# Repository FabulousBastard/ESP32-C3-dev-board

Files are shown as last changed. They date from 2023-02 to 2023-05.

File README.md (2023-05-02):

# ESP32-C3-dev-board

does not work
  - get's power 
  - isn't recognized by Windows
  
 possibel reasons 
  - soldering error
  - PCB design 
  - wong part's selection 
  - software issue 

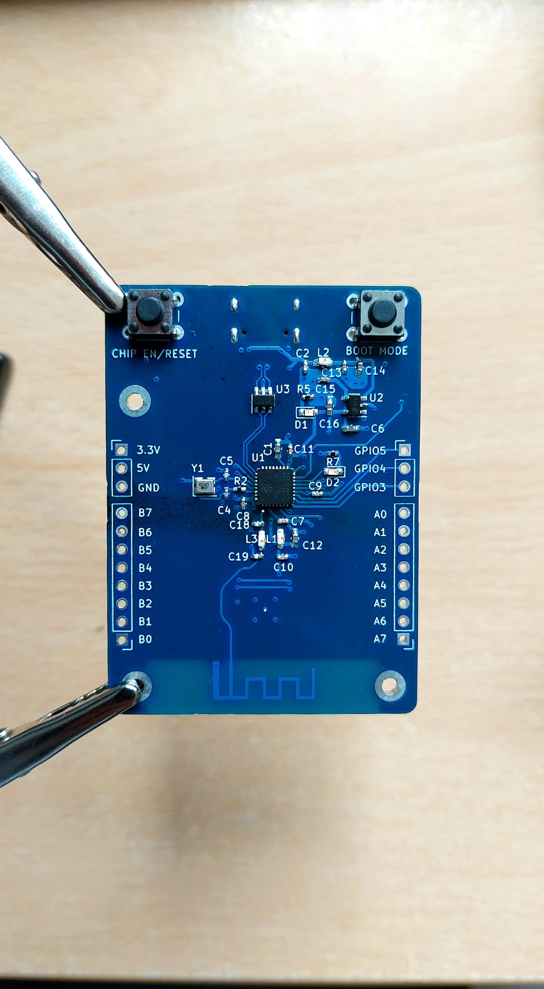
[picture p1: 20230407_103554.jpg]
  

  

  



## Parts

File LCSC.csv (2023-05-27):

LCSC Part Number | Manufacture Part Number | Manufacturer | Customer NO. | Package | Description | RoHS | Order Qty. | Min\Mult Order Qty. | Unit Price | Order Price
C319148 | U262-161N-4BVC11 | XKB Connectivity | 001 | SMD | 3A USB 3.1 1 260℃ Surface Mount 16 Female -40℃~+85℃ Gold Copper Alloy Type-C SMD USB Connectors ROHS | YES | 2 | 1\1 | 0.402600 | 0.81
C2858491 | ESP32-C3FH4 | Espressif Systems | 001 | QFN-32-EP(5x5) | QFN-32-EP(5x5) RF Transceiver ICs ROHS | YES | 2 | 1\1 | 1.968000 | 3.94
C9055 | SPX3819M5-L-3-3/TR | MaxLinear | 001 | SOT-23-5 | 500mA 70dB Fixed 3.3V~3.3V Positive 16V SOT-23-5 Linear Voltage Regulators (LDO) ROHS | YES | 5 | 5\5 | 0.167900 | 0.84
C7519 | USBLC6-2SC6 | STMicroelectronics | 001 | SOT-23-6 | 6V 17V Unidirectional 5.25V SOT-23-6 ESD Protection Devices ROHS | YES | 5 | 5\5 | 0.128900 | 0.64
C2940200 | TAXM40M4SCBDDT2T | TAE(Zhejiang Abel Elec) | 001 | SMD2520-4P | 40MHz 9pF ±10ppm SMD2520-4P Crystals ROHS | YES | 5 | 5\5 | 0.110700 | 0.55
C455091 | TS-1002-05026 | XUNPU | 001 | Plugin,6x6mm | 50mA Straight SPST 12V Plugin,6x6mm Tactile Switches ROHS | YES | 10 | 10\10 | 0.040400 | 0.40
C346308 | FEC0603CP-2N2G-LRH | PSA(Prosperity Dielectrics) | 001 | 0603 | 700mA 2.2nH ±2% 5mΩ 0603 Inductors (SMD) ROHS | YES | 10 | 10\10 | 0.041400 | 0.41
C2337 | C2337 | BOOMELE(Boom Precision Elec) | 001 | Plugin,P=2.54mm | 3A Straight Square Pins -25℃~+85℃ 40 2.54mm Plugin Black 1x40P Plugin,P=2.54mm Pin Headers ROHS | YES | 5 | 5\5 | 0.113700 | 0.57
C2846646 | SML-311UTT86J | ROHM Semicon | 001 | 0603 | -30℃~+85℃ 620nm~630nm Orange-red 44mW 0603 Light Emitting Diodes (LED) ROHS | YES | 5 | 5\5 | 0.143900 | 0.72
C2980184 | 19-217/GHC-YN1P2B18X/3T | Everlight Elec | 001 | 0603 | Colorless transparence -40℃~+85℃ Positive post 520nm~535nm Emerald 120° 95mW 0603 Light Emitting Diodes (LED) ROHS | YES | 5 | 5\5 | 0.087100 | 0.44
C321446 | RC-02W3240FT | FH (Guangdong Fenghua Advanced Tech) | 001 | 0402 | 62.5mW ±1% ±200ppm/℃ 324Ω 0402 Chip Resistor - Surface Mount ROHS | YES | 100 | 100\100 | 0.000400 | 0.04
C25543 | 0402WGJ0102TCE | UNI-ROYAL(Uniroyal Elec) | 001 | 0402 | 62.5mW Thick Film Resistors ±100ppm/℃ ±5% 1kΩ 0402 Chip Resistor - Surface Mount ROHS | YES | 200 | 100\100 | 0.000400 | 0.08
C25152 | 0402WGJ0220TCE | UNI-ROYAL(Uniroyal Elec) | 001 | 0402 | 62.5mW Thick Film Resistors ±100ppm/℃ ±5% 22Ω 0402 Chip Resistor - Surface Mount ROHS | YES | 100 | 100\100 | 0.000400 | 0.04
C2906948 | FRC0402J512 TS | FOJAN | 001 | 0402 | 62.5mW Thick Film Resistors ±100ppm/℃ ±5% 5.1kΩ 0402 Chip Resistor - Surface Mount ROHS | YES | 100 | 100\100 | 0.000500 | 0.05
C123483 | 0402N3R3B500CT | Walsin Tech Corp | 001 | 0402 | 50V 3.3pF NP0 0402 Multilayer Ceramic Capacitors MLCC - SMD/SMT ROHS | YES | 100 | 100\100 | 0.002200 | 0.22
C161507 | GRM1552C1H8R0BA01D | Murata Electronics | 001 | 0402 | 50V 8pF CH 0402 Multilayer Ceramic Capacitors MLCC - SMD/SMT ROHS | YES | 50 | 50\50 | 0.006900 | 0.35
C392963 | TCC0402X7R104K160AT | CCTC | 001 | 0402 | 16V 100nF X7R ±10% 0402 Multilayer Ceramic Capacitors MLCC - SMD/SMT ROHS | YES | 100 | 100\100 | 0.000900 | 0.09
C5252392 | V106M0402X5R100NCT | VIIYONG | 001 | 0402 | 10V 10uF X5R 0402 Multilayer Ceramic Capacitors MLCC - SMD/SMT ROHS | YES | 50 | 50\50 | 0.009700 | 0.49
C629442 | MCP23S17T-E/ML | Microchip Tech | 001 | QFN-28-EP(6x6) | 10MHz SPI QFN-28-EP(6x6) I/O Expanders ROHS | YES | 2 | 1\1 | 5.956400 | 11.91

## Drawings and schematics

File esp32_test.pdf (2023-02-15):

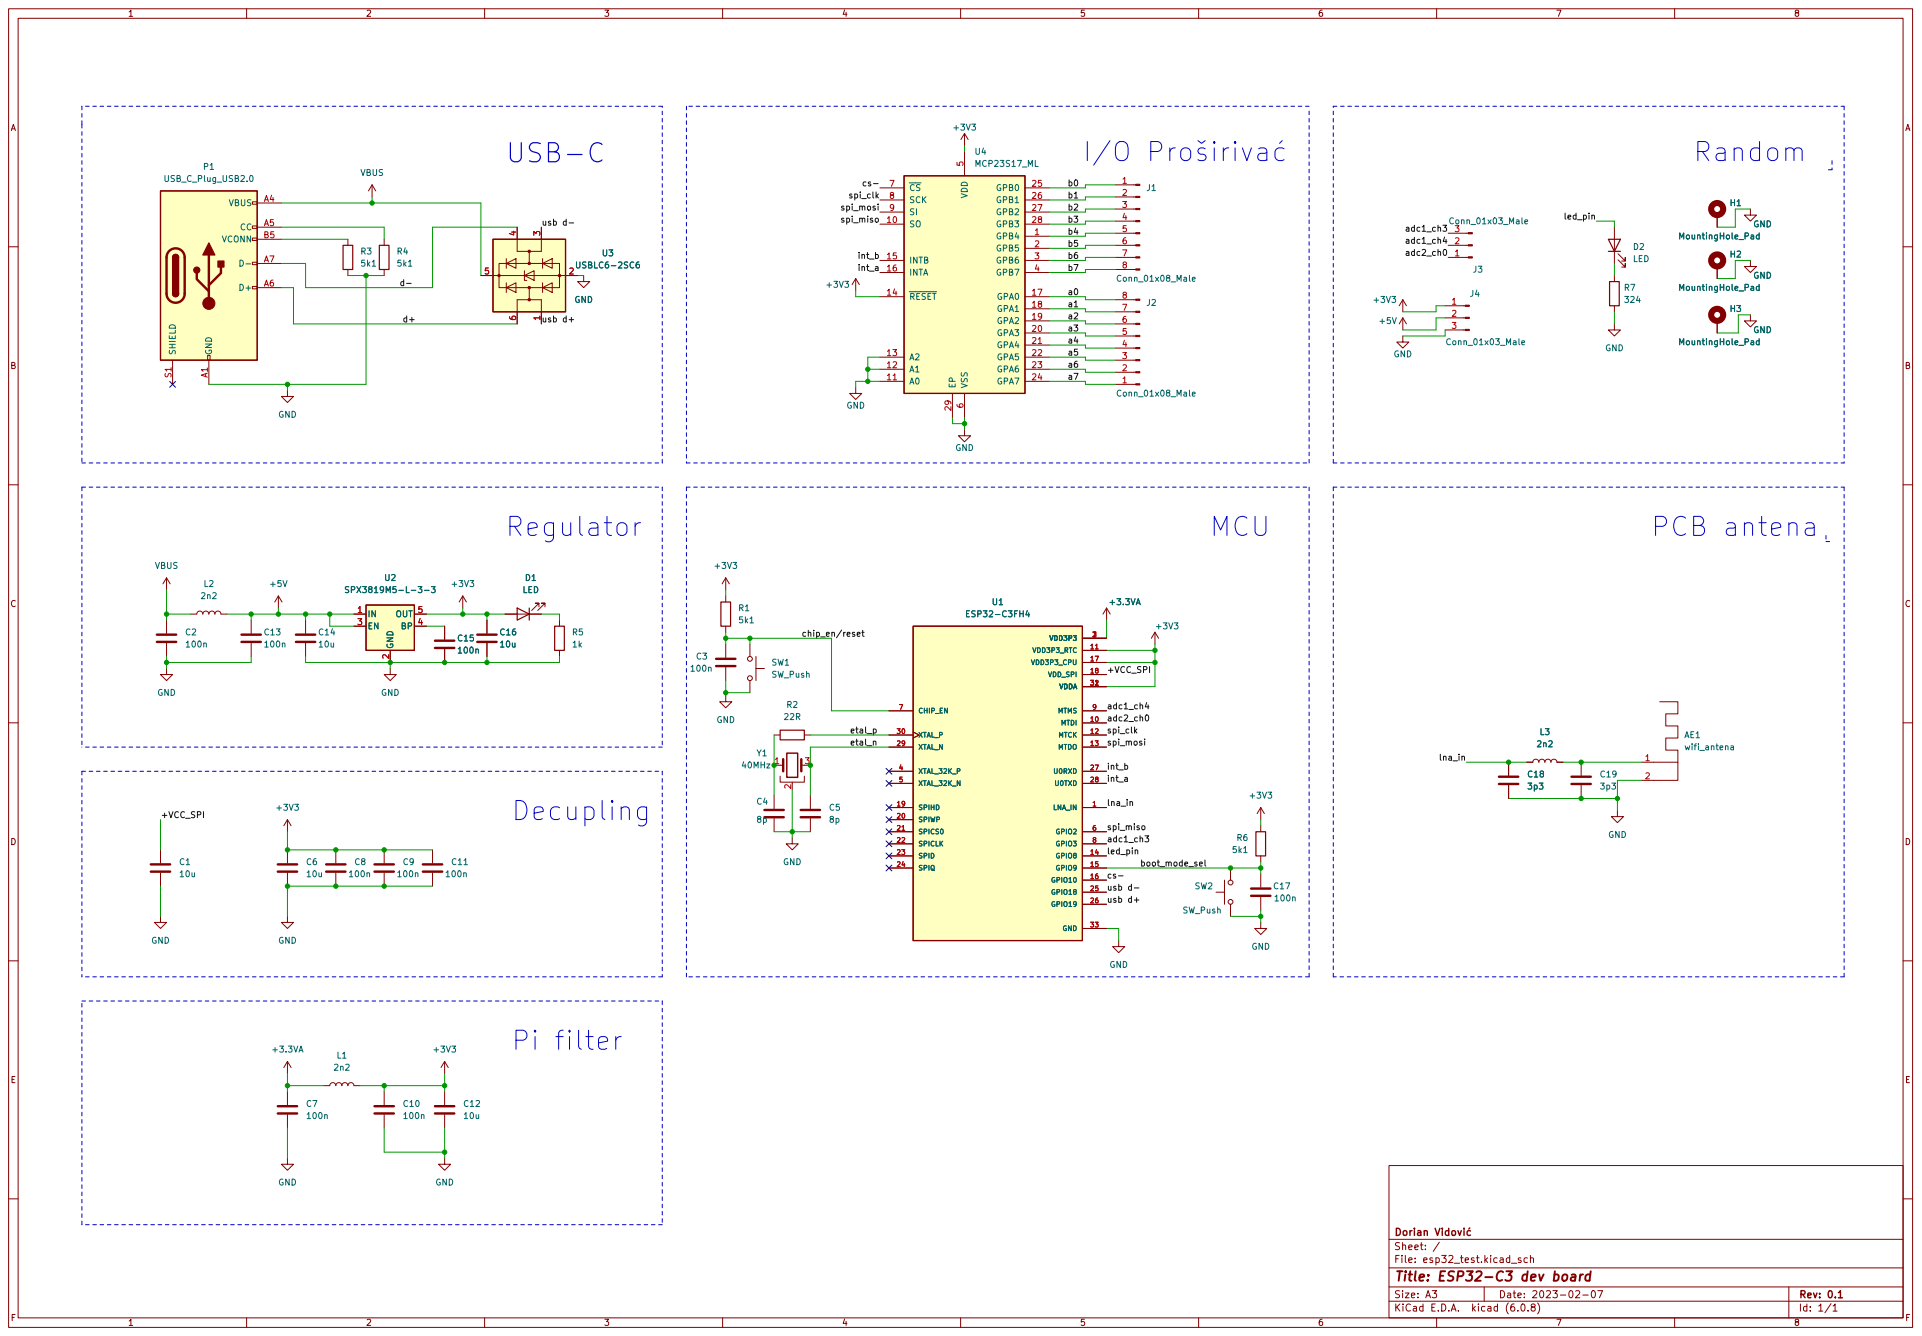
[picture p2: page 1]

Id: 1/1 Title: ESP32-C3 dev board

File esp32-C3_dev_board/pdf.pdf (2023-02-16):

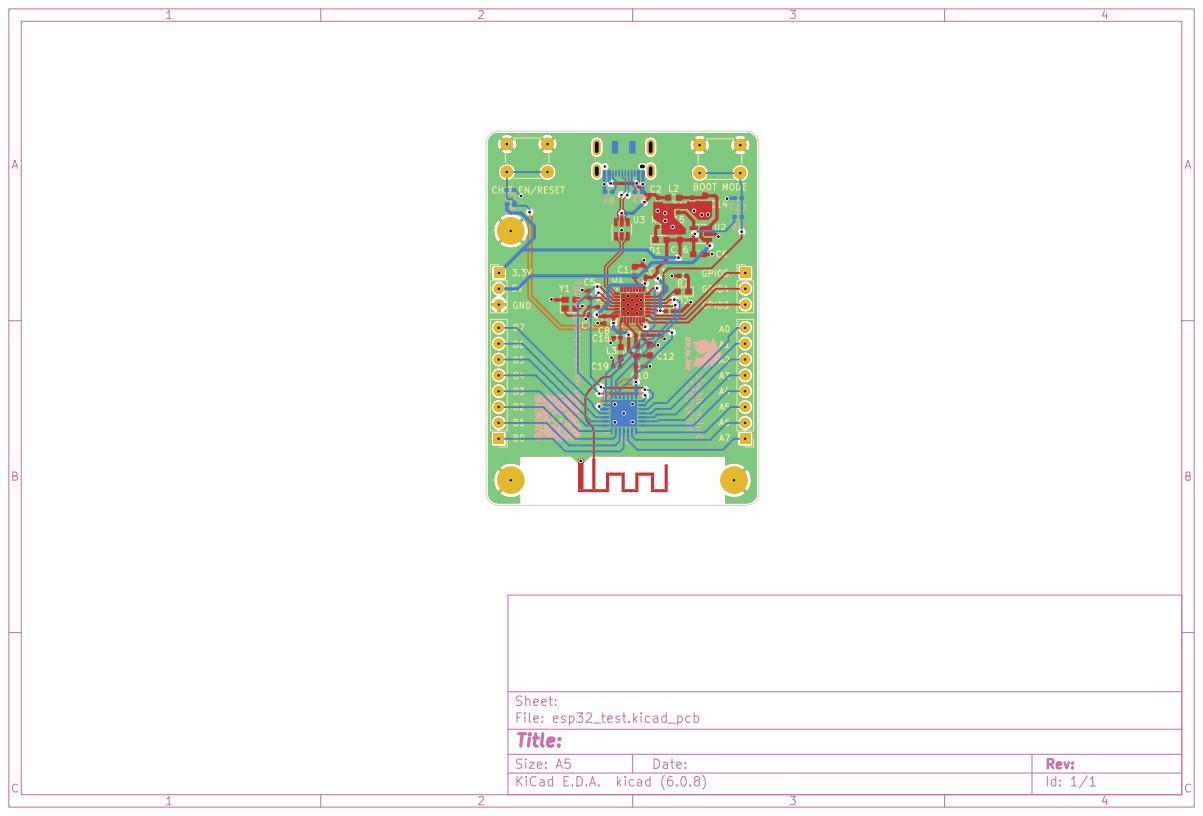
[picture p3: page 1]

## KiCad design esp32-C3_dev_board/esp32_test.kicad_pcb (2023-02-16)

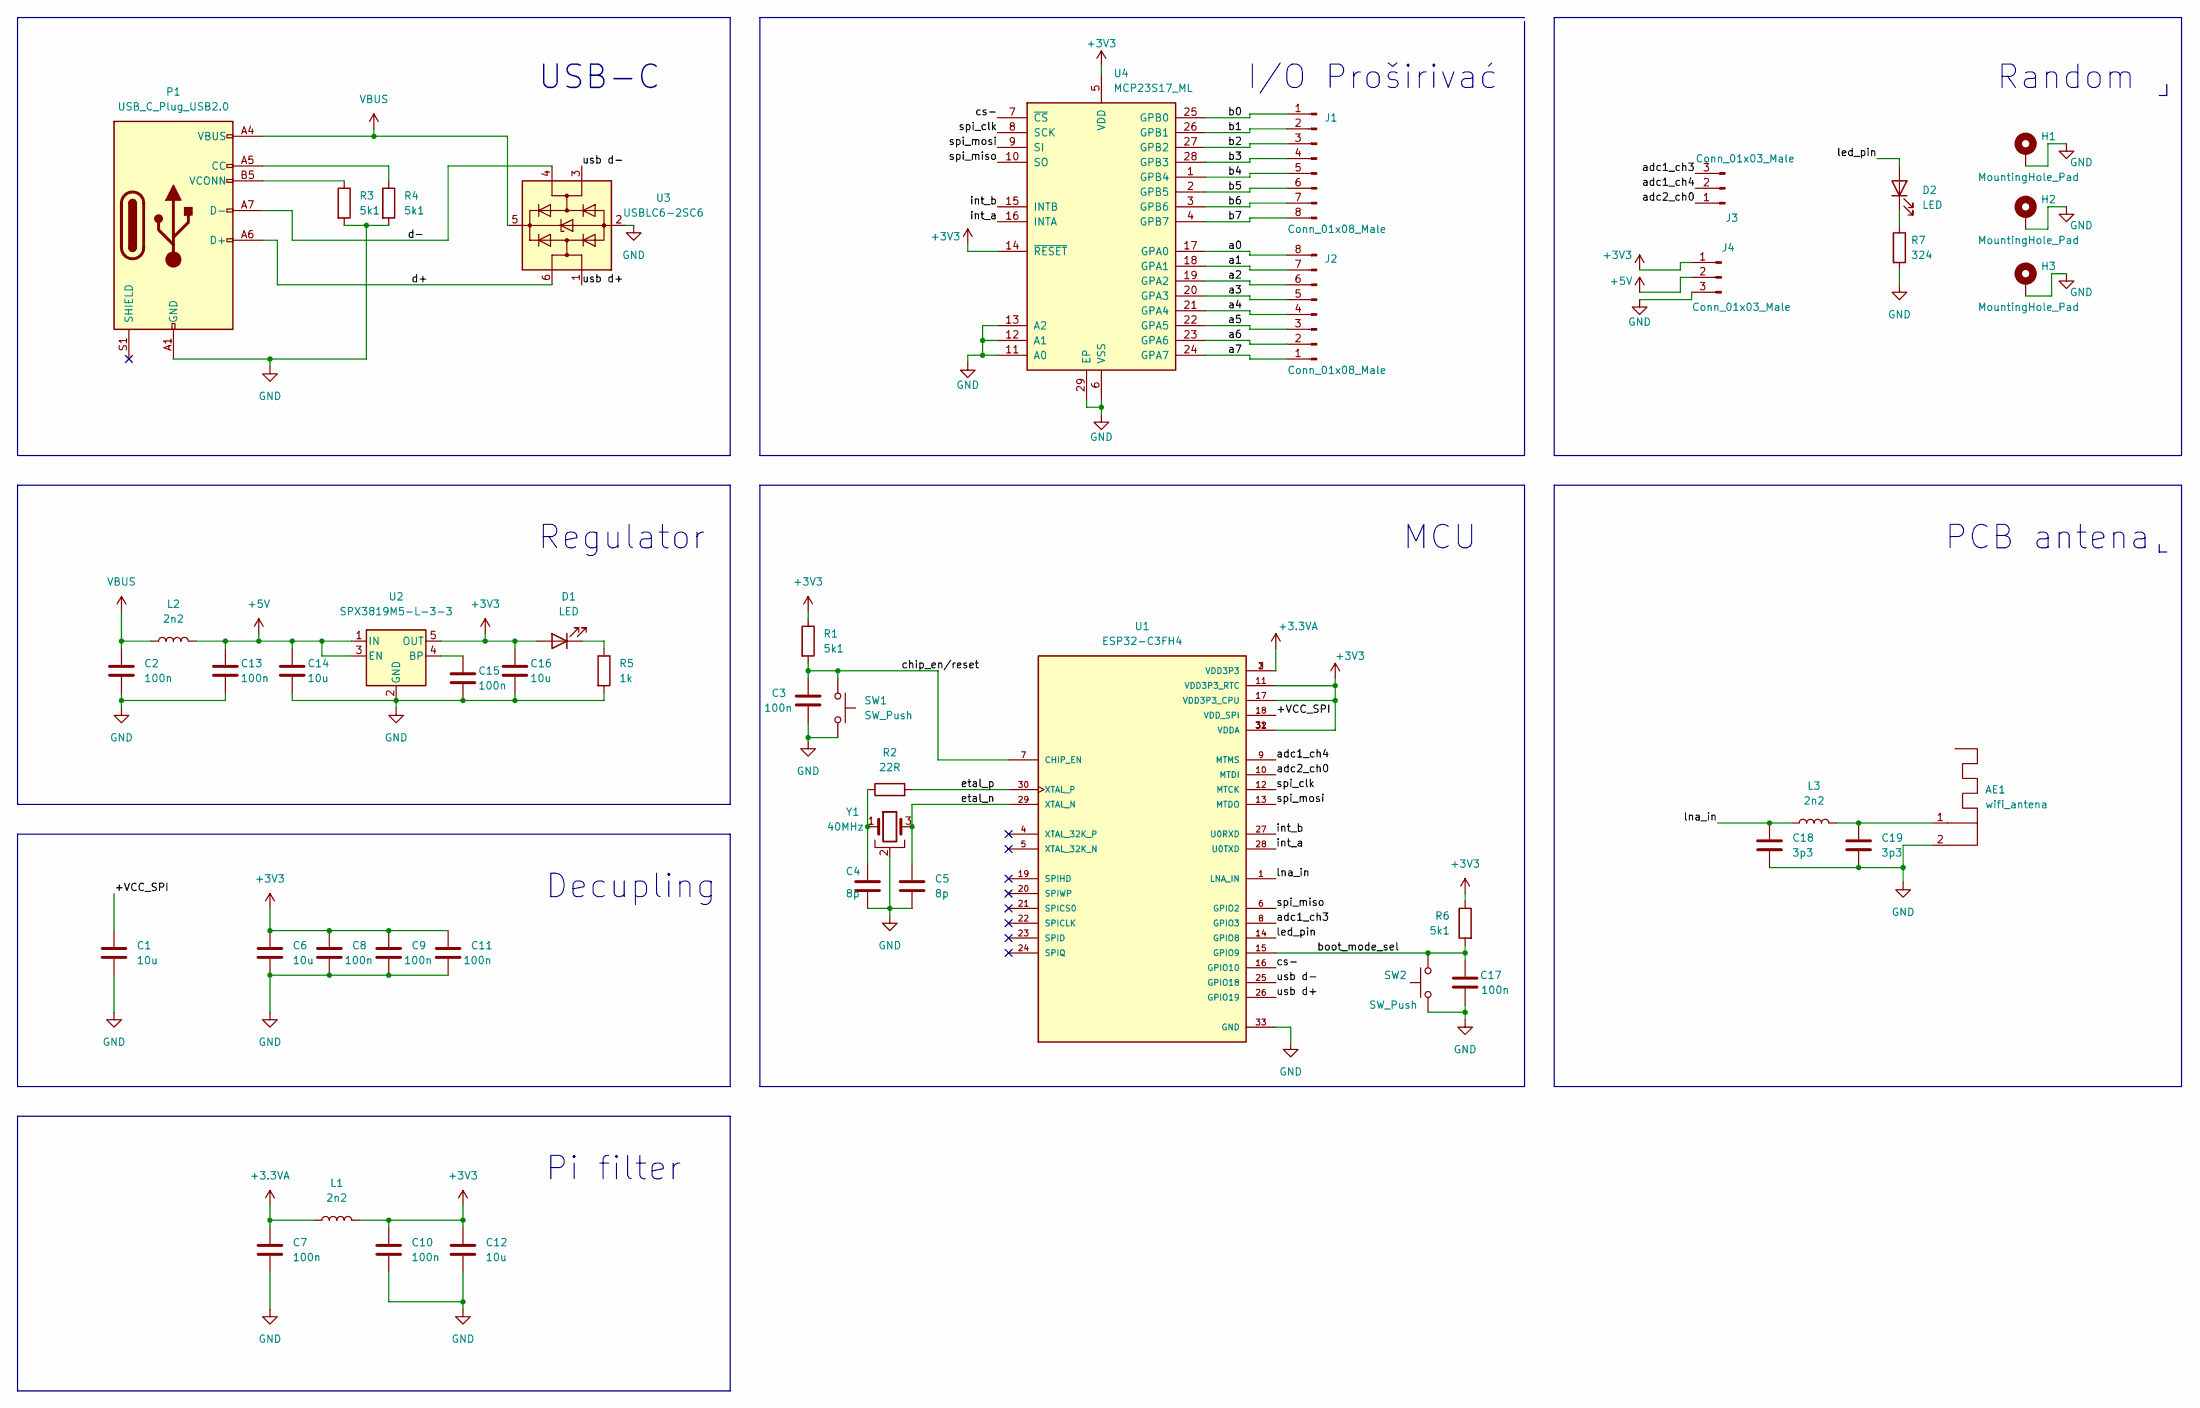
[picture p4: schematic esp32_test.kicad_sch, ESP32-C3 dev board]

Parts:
AE1: wifi_antena
C1: 10u; C_0603_1608Metric
C2, C3, C7, C8, C9, C10, C11, C13, C15, C17: 100n; C_0402_1005Metric_Pad0.74x0.62mm_HandSolder
C4, C5: 8p; C_0402_1005Metric_Pad0.74x0.62mm_HandSolder
C6, C12, C14, C16: 10u; C_0603_1608Metric_Pad1.08x0.95mm_HandSolder
C18, C19: 3p3; C_0402_1005Metric_Pad0.74x0.62mm_HandSolder
D1, D2: LED; LED_0603_1608Metric_Pad1.05x0.95mm_HandSolder
H1, H2, H3: MountingHole_Pad; MountingHole_2.2mm_M2_Pad
J1, J2: Conn_01x08_Male; PinHeader_1x08_P2.54mm_Vertical
J3, J4: Conn_01x03_Male; PinHeader_1x03_P2.54mm_Vertical
L1, L2, L3: 2n2; L_0603_1608Metric_Pad1.05x0.95mm_HandSolder
P1: USB_C_Plug_USB2.0; USB_C_Receptacle_JAE_DX07S016JA1R1500
R1, R3, R4, R6: 5k1; R_0402_1005Metric_Pad0.72x0.64mm_HandSolder
R2: 22R; R_0402_1005Metric_Pad0.72x0.64mm_HandSolder
R5: 1k; R_0402_1005Metric_Pad0.72x0.64mm_HandSolder
R7: 324; R_0402_1005Metric_Pad0.72x0.64mm_HandSolder
SW1, SW2: SW_Push; SW_PUSH_6mm_H5mm
U1: ESP32-C3FH4; QFN50P500X500X90-33N; PARTREV V1.0
U2: SPX3819M5-L-3-3; SOT-23-5
U3: USBLC6-2SC6; SOT-23-6
U4: MCP23S17_ML; QFN-28-1EP_6x6mm_P0.65mm_EP4.25x4.25mm
Y1: 40MHz; Crystal_SMD_2520-4Pin_2.5x2.0mm

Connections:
+3.3VA: C7.1, L1.1, U1.2 (VDD3P3), U1.3 (VDD3P3)
+3V3: C6.1, C8.1, C9.1, C10.1, C11.1, C12.1, C16.1, D1.2 (A), J4.1, L1.2, R1.1, R6.1, U1.11 (VDD3P3_RTC), U1.17 (VDD3P3_CPU), U1.31 (VDDA), U1.32 (VDDA), U2.5 (OUT), U4.5 (VDD), U4.14 (~RESET)
+5V: C13.1, C14.1, J4.2, L2.2, U2.1 (IN), U2.3 (EN)
/+VCC_SPI: C1.1, U1.18 (VDD_SPI)
/a0: J2.8, U4.17 (GPA0)
/a1: J2.7, U4.18 (GPA1)
/a2: J2.6, U4.19 (GPA2)
/a3: J2.5, U4.20 (GPA3)
/a4: J2.4, U4.21 (GPA4)
/a5: J2.3, U4.22 (GPA5)
/a6: J2.2, U4.23 (GPA6)
/a7: J2.1, U4.24 (GPA7)
/adc1_ch3: J3.3, U1.8 (GPIO3)
/adc1_ch4: J3.2, U1.9 (MTMS)
/adc2_ch0: J3.1, U1.10 (MTDI)
/b0: J1.1, U4.25 (GPB0)
/b1: J1.2, U4.26 (GPB1)
/b2: J1.3, U4.27 (GPB2)
/b3: J1.4, U4.28 (GPB3)
/b4: J1.5, U4.1 (GPB4)
/b5: J1.6, U4.2 (GPB5)
/b6: J1.7, U4.3 (GPB6)
/b7: J1.8, U4.4 (GPB7)
/boot_mode_sel: C17.1, R6.2, SW2.2, U1.15 (GPIO9)
/chip_en/reset: C3.1, R1.2, SW1.1, U1.7 (CHIP_EN)
/cs-: U1.16 (GPIO10), U4.7 (~CS)
/d+: P1.A6 (D+), U3.6 (I/O1)
/d-: P1.A7 (D-), U3.4 (I/O2)
/etal_n: C5.1, U1.29 (XTAL_N), Y1.3
/etal_p: R2.2, U1.30 (XTAL_P)
/int_a: U1.28 (U0TXD), U4.16 (INTA)
/int_b: U1.27 (U0RXD), U4.15 (INTB)
/led_pin: D2.2 (A), U1.14 (GPIO8)
/lna_in: C18.1, L3.1, U1.1 (LNA_IN)
/spi_clk: U1.12 (MTCK), U4.8 (SCK)
/spi_miso: U1.6 (GPIO2), U4.10 (SO)
/spi_mosi: U1.13 (MTDO), U4.9 (SI)
/usb d+: U1.26 (GPIO19), U3.1 (I/O1)
/usb d-: U1.25 (GPIO18), U3.3 (I/O2)
GND: AE1.2, C1.2, C2.2, C3.2, C4.2, C5.2, C6.2, C7.2, C8.2, C9.2, C10.2, C11.2, C12.2, C13.2, C14.2, C15.2, C16.2, C17.2, C18.2, C19.2, H1.1, H2.1, H3.1, J4.3, P1.A1 (GND), P1.A12 (GND), P1.B1 (GND), P1.B12 (GND), R3.2, R4.2, R5.2, R7.2, SW1.2, SW2.1, U1.33 (GND), U1.34, U1.35, U1.36, U1.38, U1.40, U1.41, U1.42, U1.43, U1.45, U1.47, U1.48, U1.49, U2.2 (GND), U3.2 (GND), U4.6 (VSS), U4.11 (A0), U4.12 (A1), U4.13 (A2), U4.29 (EP), Y1.2, Y1.4
unnamed: AE1.1, C19.1, L3.2
unnamed: C4.1, R2.1, Y1.1
unnamed: C15.1, U2.4 (BP)
unnamed: D1.1 (K), R5.1
unnamed: D2.1 (K), R7.1
unnamed: P1.A5 (CC), R4.1
unnamed: P1.B5 (VCONN), R3.1
VBUS: C2.1, L2.1, P1.A4 (VBUS), P1.A9 (VBUS), P1.B4 (VBUS), P1.B9 (VBUS), U3.5 (VBUS)

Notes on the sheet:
Decupling
I/O Proširivać
MCU
PCB antena
Random
USB-C
Regulator
Pi filter

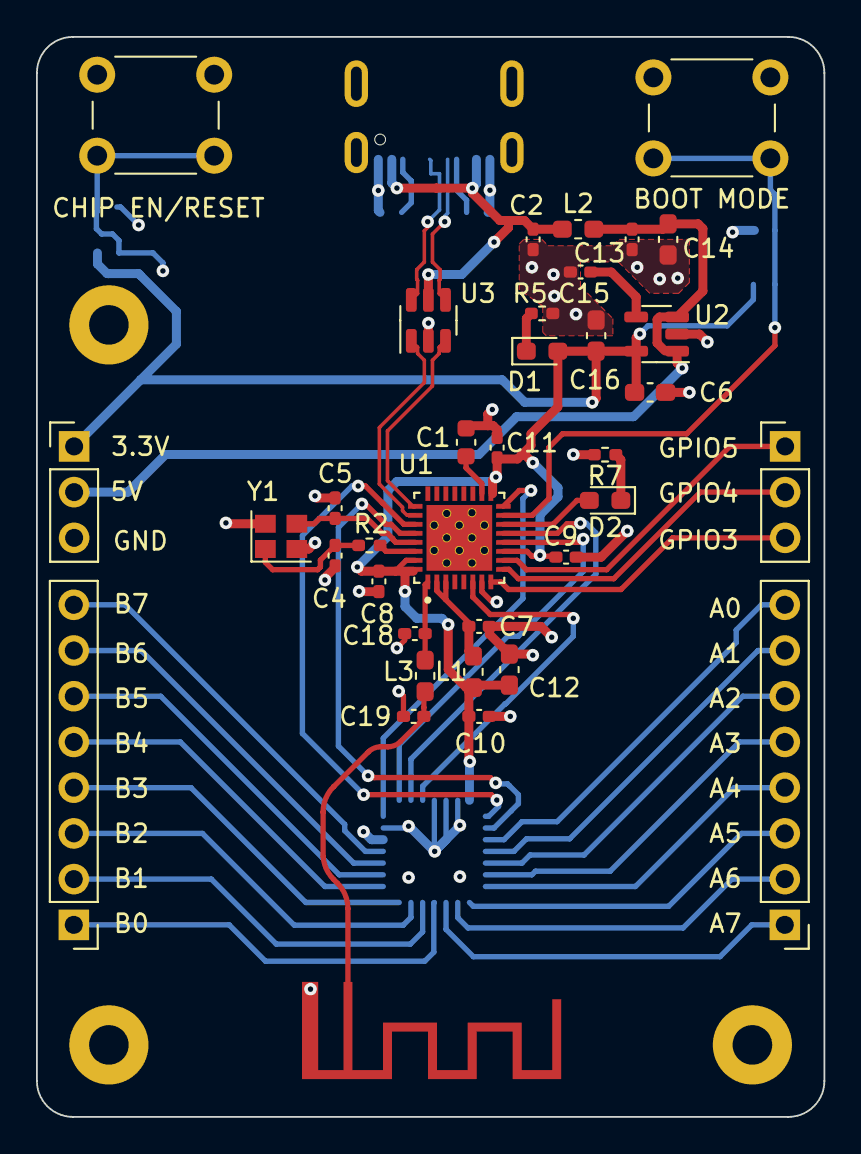
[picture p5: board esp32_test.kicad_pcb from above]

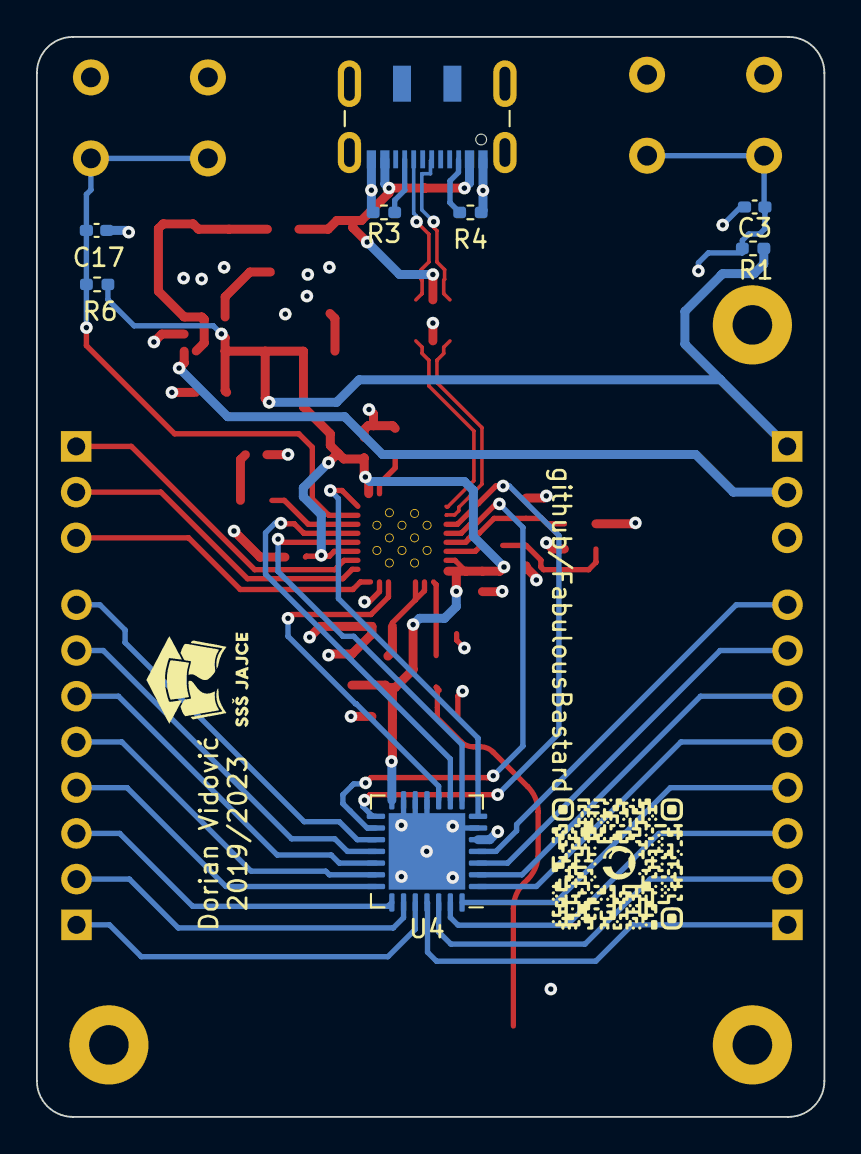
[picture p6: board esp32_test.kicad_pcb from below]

Board: 4 copper layers, 43.8 x 60.0 mm, 47 parts (8 on the bottom side), 48 nets.
